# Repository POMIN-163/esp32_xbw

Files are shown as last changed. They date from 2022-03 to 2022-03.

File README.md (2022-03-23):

# 一个基于VGA显示器的小霸王复刻

> 本仓库主要克隆自 [https://github.com/eleree/xbw](https://github.com/eleree/xbw)，做了一些修改、对复现的过程进行了一些完善

## 硬件制作

* 因为我是手焊，所以删去了较难焊的 16pin type-c 并把电阻电容换成了 0805 封装。

* 主板
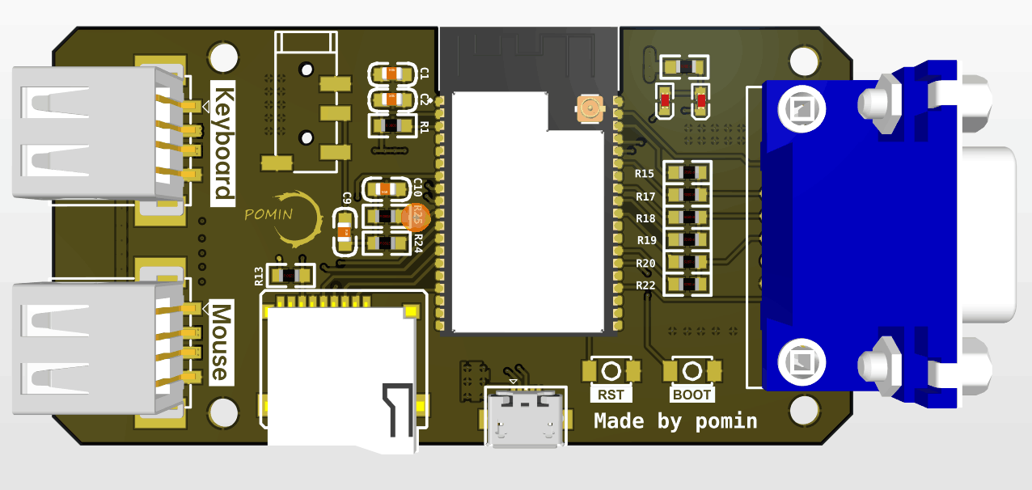
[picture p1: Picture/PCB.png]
    
* 盖板
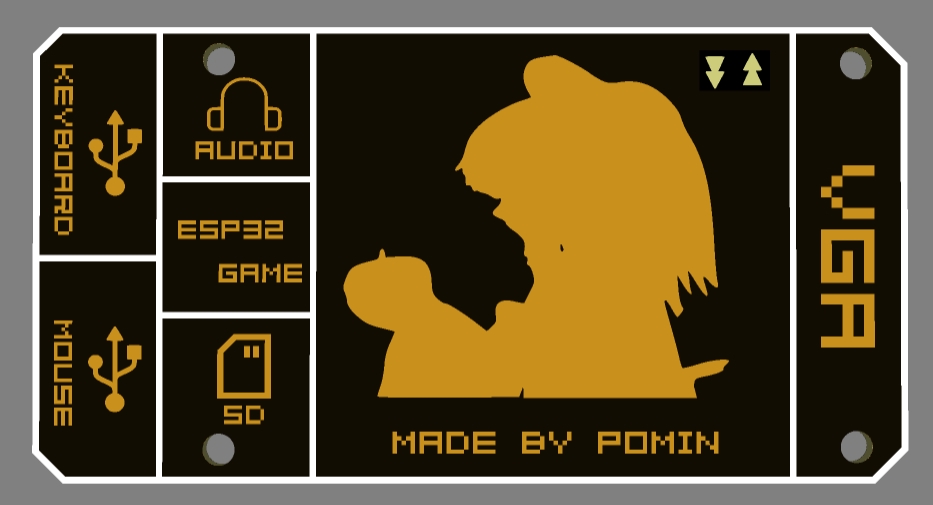
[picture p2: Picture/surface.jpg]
    
* 转接板
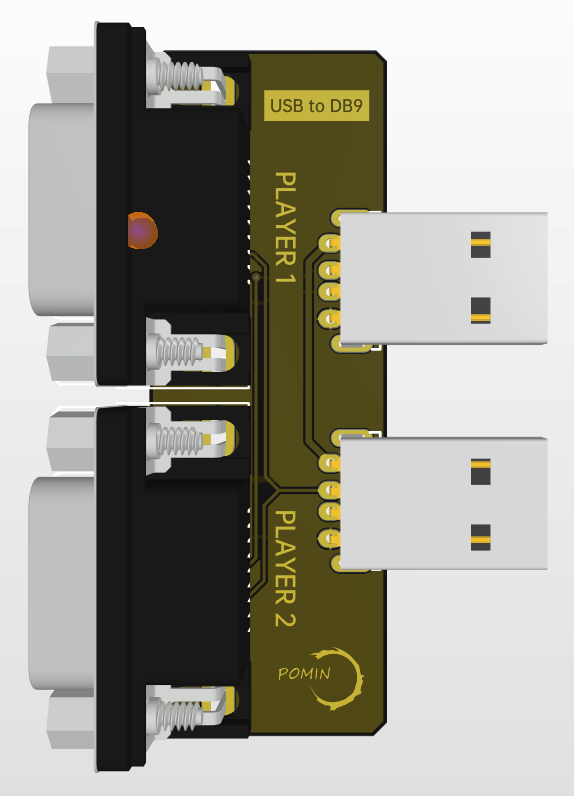
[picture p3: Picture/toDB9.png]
    
* 实物外观
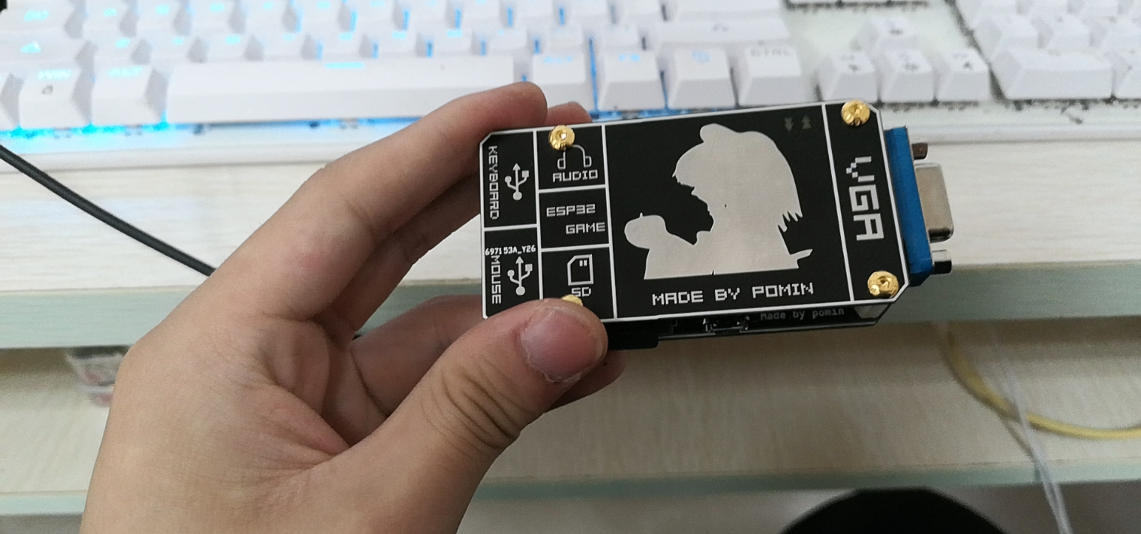
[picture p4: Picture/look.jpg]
    

## 固件编译

* 硬件平台：ESP32-WROVER-E
* 软件平台：ESP32-IDF V3.3.5
* 编译环境：Ubuntu18.04 (WSL)
* Python版本：python2.7

> esp-idf3.3.5 官方文档: [https://docs.espressif.com/projects/esp-idf/zh_CN/v3.3.5/](https://docs.espressif.com/projects/esp-idf/zh_CN/v3.3.5/)

使用的 Ubuntu18.04 中默认 `python` 是 `python2.7`，`python2.7`没有自带`pip`工具，可以我的博客 [https://pomin.top/](https://pomin.top/) 中搜索`python2`的`pip`安装，来按照教程进行安装。

* 克隆储存库并安装

```
cd ~
git clone -b v3.3.5 --recursive https://github.com/espressif/esp-idf.git
cd esp-idf
./install.sh
```

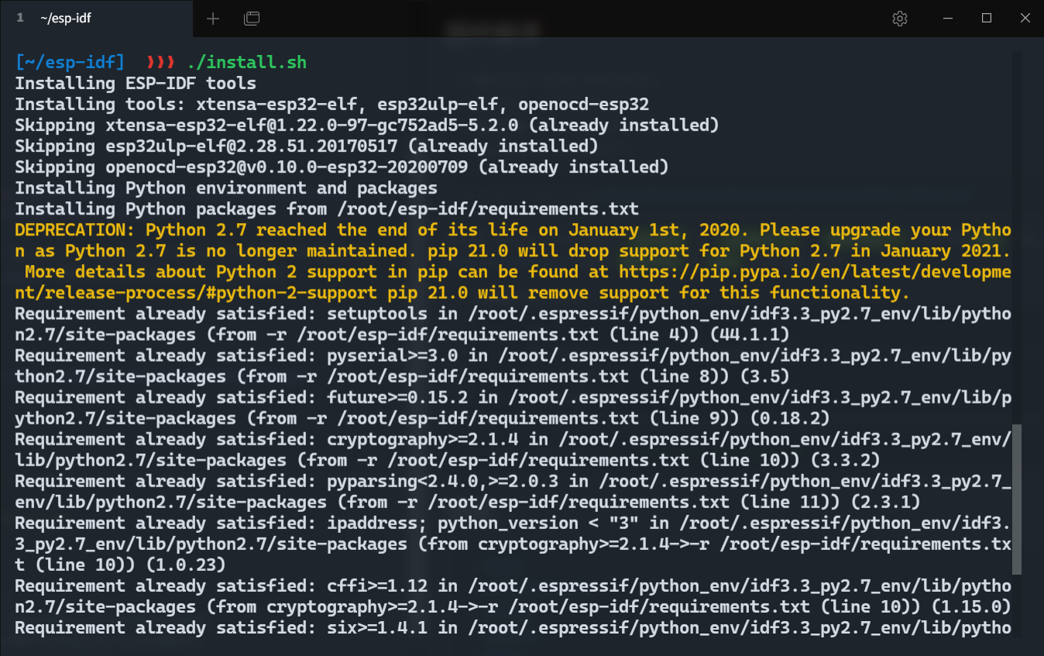
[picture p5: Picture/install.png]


* 外部包含 ( 每次启动终端都要执行 )

```bash
. /root/esp-idf/export.sh
```

* 编译 ( 本仓库采用 gnu make 进行编译 )

```bash
# cd 到仓库的 Code 目录
make -j8 all
```

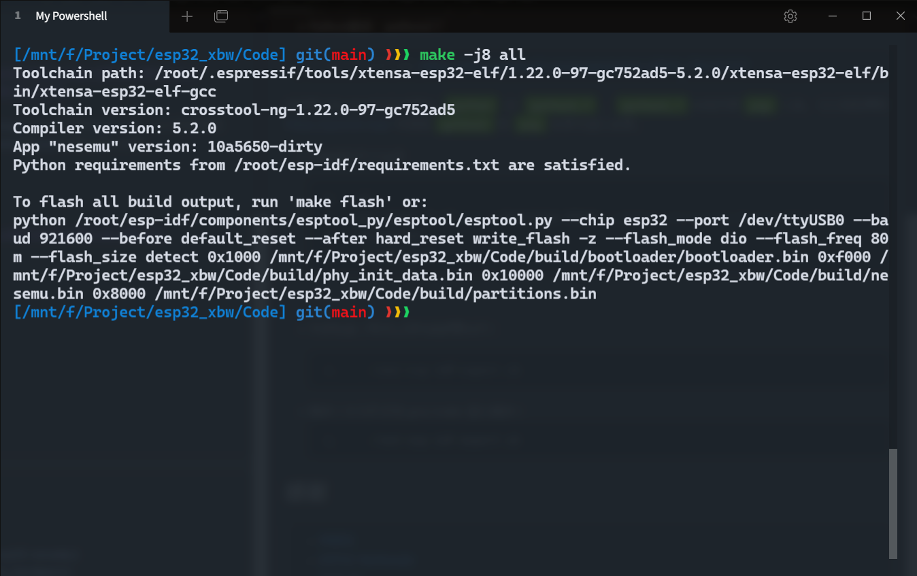
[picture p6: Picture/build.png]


* 烧录 ( 端口号、烧录速率需要自己设置这里是`ttyS22` 也就是 Windows 设备管理器的 `COM22` )

```bash
. ${IDF_PATH}/add_path.sh
esptool.py --chip esp32 --port "/dev/ttyS22" --baud $((230400*4)) write_flash -fs 4MB 0x100000 "build/nesemu.bin"
```

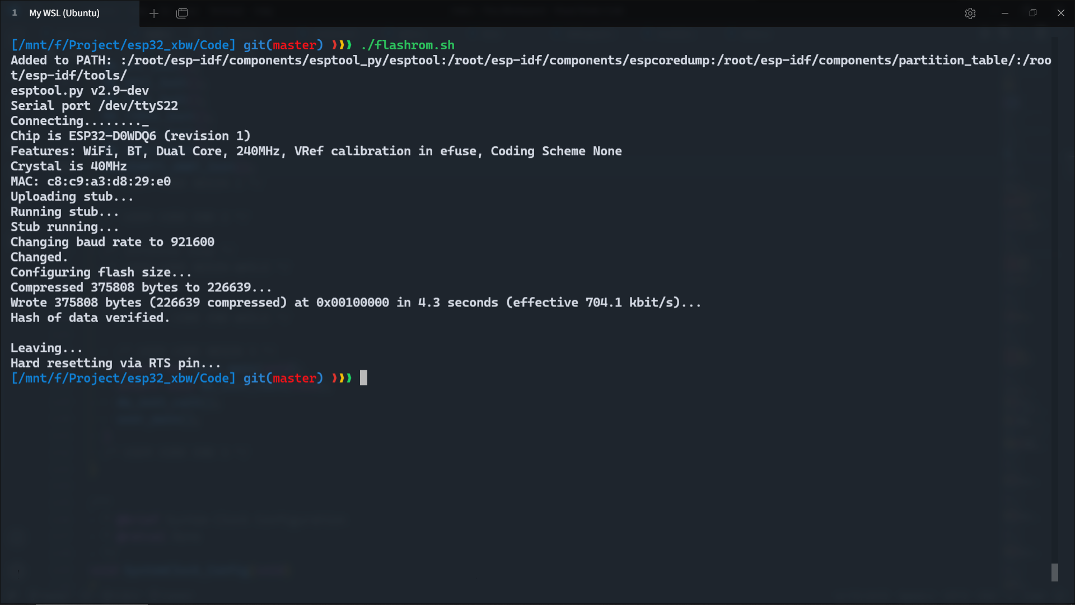
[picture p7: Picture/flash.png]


## 演示

* 运行 `arduino` 的 `fabgl` 库的 `VIC20` 例程玩俄罗斯方块
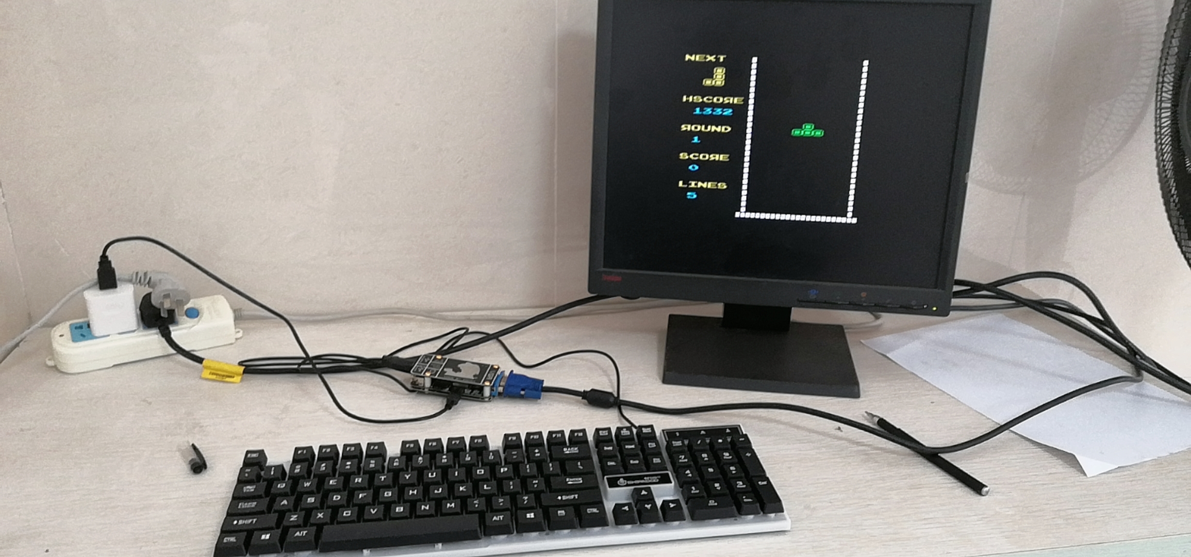
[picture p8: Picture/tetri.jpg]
    
* 运行 [秦秦心](https://github.com/eleree/xbw) 开源的基于`idf3.3.5`开发的 nes 游戏机
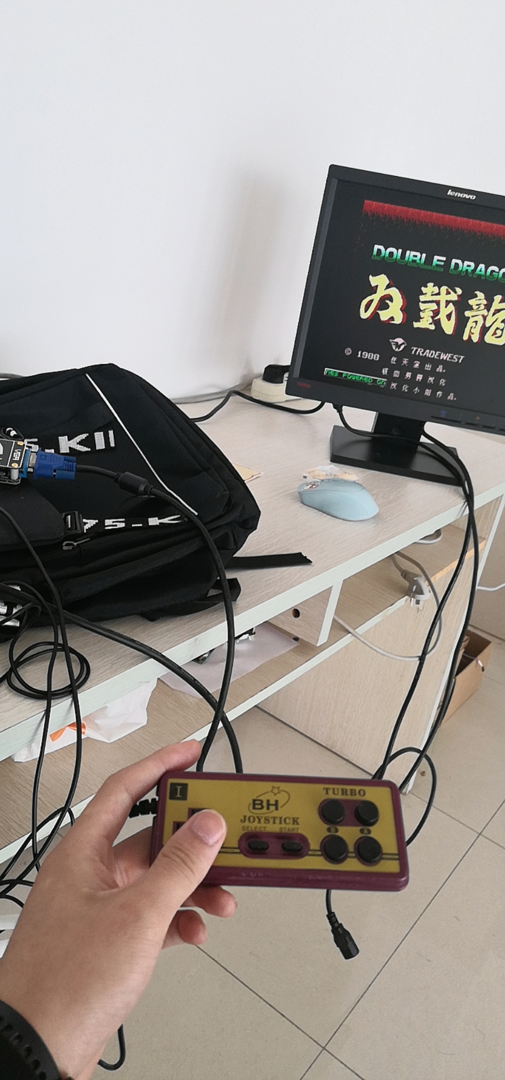
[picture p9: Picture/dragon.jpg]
    

## 感谢以下开源
> * [FABGL](http://www.fabglib.org/)
> * [ESP32-Nofrendo](https://github.com/espressif/esp32-nesemu)
> * [ESPLAY](https://github.com/pebri86/esplay_micro_hardware)
> * [吐槽坑儿](https://space.bilibili.com/31312385)
> * [秦秦心](https://github.com/eleree/xbw)

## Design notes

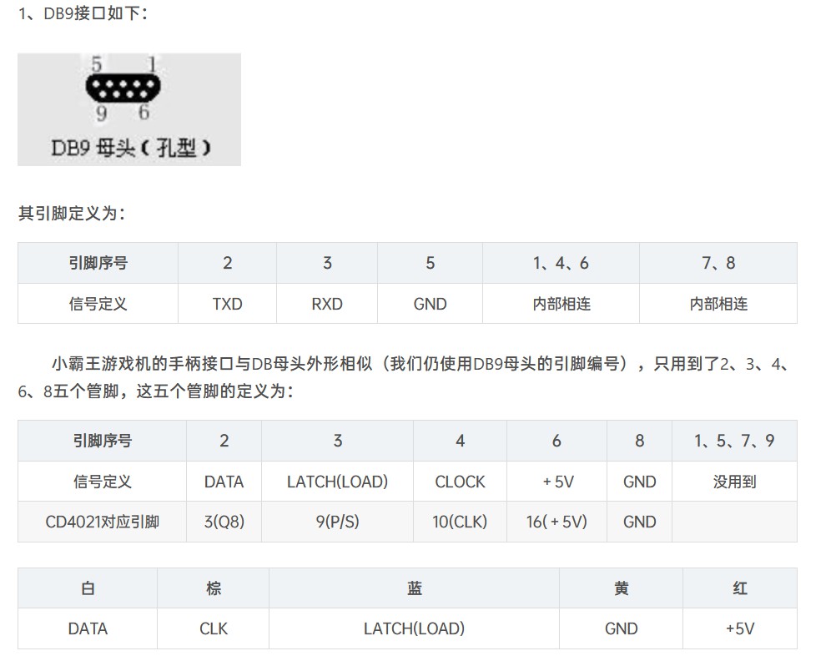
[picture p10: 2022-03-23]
Hardware/USBtoDB9/define.jpg

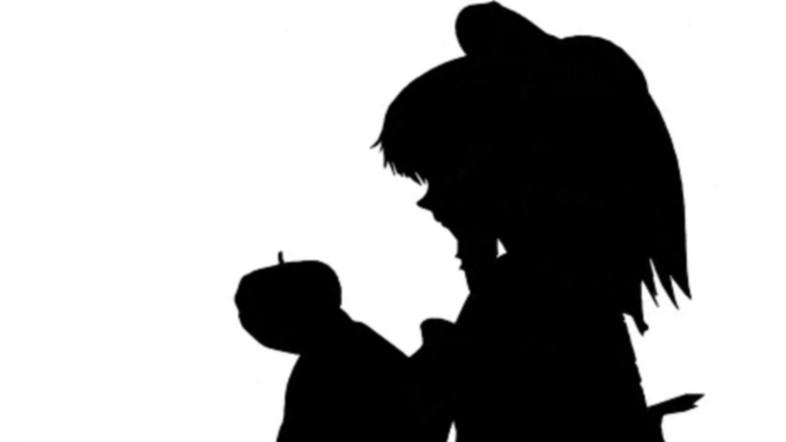
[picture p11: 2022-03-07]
Hardware/surface/apple.jpg

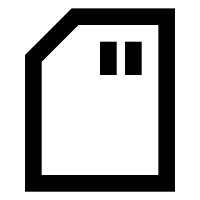
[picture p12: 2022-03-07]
Hardware/surface/SD.png

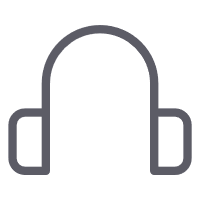
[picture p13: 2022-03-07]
Hardware/surface/audio.png

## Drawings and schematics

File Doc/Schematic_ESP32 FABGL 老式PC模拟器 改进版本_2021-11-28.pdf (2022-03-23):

键盘

音频

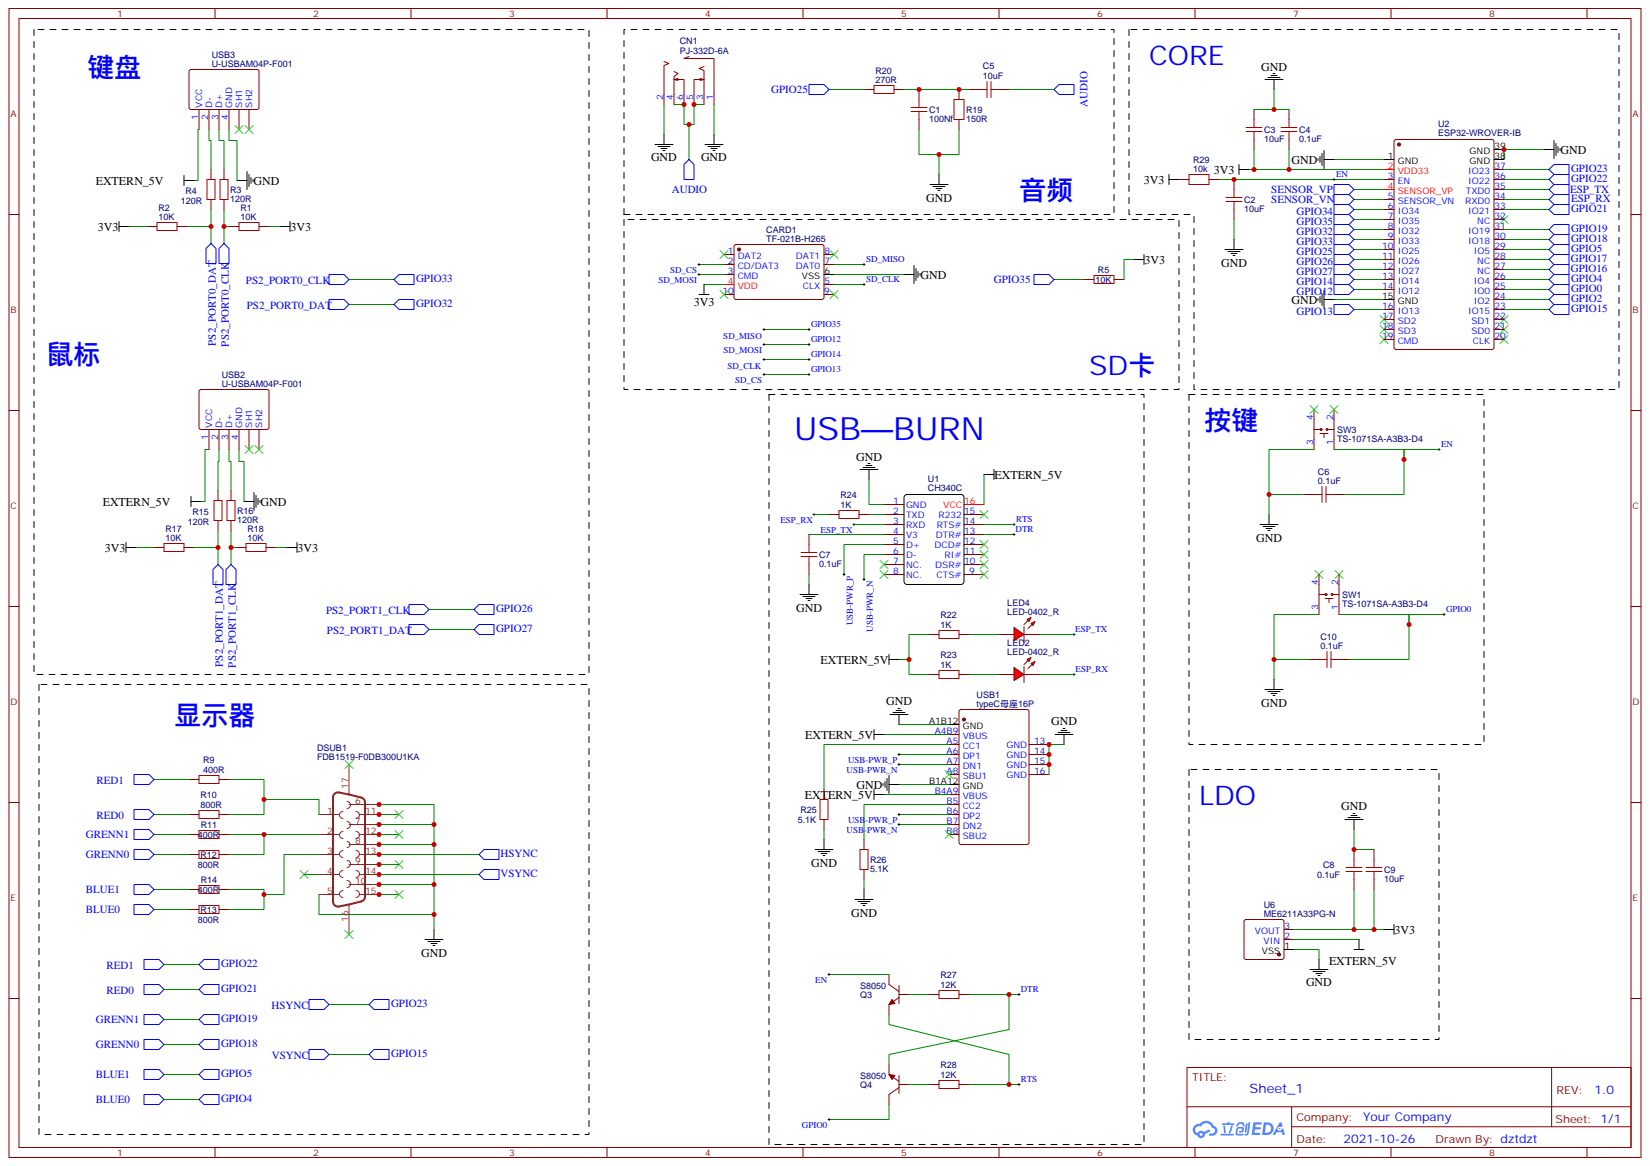
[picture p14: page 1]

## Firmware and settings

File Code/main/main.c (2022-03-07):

#include <vga16.h>

#include "driver/gpio.h"
#include "esp_event.h"
#include "esp_event_loop.h"
#include "esp_partition.h"
#include "esp_system.h"
#include "esp_wifi.h"
#include "freertos/FreeRTOS.h"
#include "nofrendo.h"
#include "nvs_flash.h"
#include "sdcard.h"

#if 0
char *osd_getromdata() {
	char* romdata;
	const esp_partition_t* part;
	spi_flash_mmap_handle_t hrom;
	esp_err_t err;
	nvs_flash_init();
	part=esp_partition_find_first(0x40, 1, NULL);
	if (part==0) printf("Couldn't find rom part!\n");
	err=esp_partition_mmap(part, 0, 3*1024*1024, SPI_FLASH_MMAP_DATA, (const void**)&romdata, &hrom);
	if (err!=ESP_OK) printf("Couldn't map rom part!\n");
	printf("Initialized. ROM@%p\n", romdata);
    return (char*)romdata;
}
#else
const char *SD_BASE_PATH = "/sd";
static char *ROM_DATA = (char *)0x3f800000;

char *osd_getromdata(void) {
    printf("Initialized. ROM@%p\n", ROM_DATA);
    return (char *)ROM_DATA;
}

#endif

esp_err_t event_handler(void *ctx, system_event_t *event) { return ESP_OK; }

void sdspi_test(void) {
    vTaskDelay(3000);
    sdcard_open("/sd");
    int count = sdcard_get_files_count("/sd/sd");
    printf("sd card files :%d\r\n", count);
    size_t file_size = sdcard_get_filesize("/sd/sd/NOTICE.txt");
    printf("sd card file size :%d\r\n", file_size);
}

void ui_init(void);
char *ui_file_chooser(const char *path, const char *filter, int currentItem,
                      char *title);
void ui_clear_screen(void);

char *romPath = NULL;
void vfs_test(void) {
    FILE *f = fopen("/sd/hello.txt", "w");
    if (f == NULL) {
        return;
    }
    fprintf(f, "Hello %s!\n", "world");
    fclose(f);
}
void load_rom(void) {
    esp_err_t ret = sdcard_open(SD_BASE_PATH);
    if (ret != ESP_OK) {
        printf("failed to open sd card\n");
        return NULL;
    }
    romPath = ui_file_chooser("/sd/roms", ".nes", 0, "Select ROM");
    if (romPath == NULL) {
        printf("No ROM selected\n");
        return;
    }
    printf("ROM: %s\n", romPath);
    sdcard_close();
    ROM_DATA = malloc(3 * 1024 * 1024);
    if (!romPath) {
        printf("osd_getromdata: Reading from flash.\n");

        // copy from flash
        // spi_flash_mmap_handle_t hrom;
        const esp_partition_t *part = esp_partition_find_first(0x40, 1, NULL);
        if (part == 0) {
            printf("esp_partition_find_first failed.\n");
            abort();
        }

        esp_err_t err = esp_partition_read(part, 0, (void *)ROM_DATA, 0x100000);
        if (err != ESP_OK) {
            printf("esp_partition_read failed. size = %x (%d)\n", part->size,
                   err);
            abort();
        }
    } else {
        printf("osd_getromdata: Reading from sdcard.\n");

        // copy from SD card
        esp_err_t r = sdcard_open(SD_BASE_PATH);
        if (r != ESP_OK) {
            abort();
        }

        // display_clear(0);
        // display_show_hourglass();
        size_t file_size = sdcard_get_filesize(romPath);
        printf("sd card file size :%d\r\n", file_size);
        vfs_test();
        size_t fileSize = sdcard_copy_file_to_memory(romPath, ROM_DATA);
        printf("app_main: fileSize=%d\n", fileSize);
        if (fileSize == 0) {
            abort();
        }

        r = sdcard_close();
        if (r != ESP_OK) {
            abort();
        }

        free(romPath);
    }
}

int app_main(void) {
    vga_init();
    vga_write_frame(0, 0, 320, 240, NULL);
    ui_init();
    load_rom();
    ui_clear_screen();
    printf("starting esp32 nofrendo\r\n");
    printf("NoFrendo start!\n");
    nofrendo_main(0, NULL);
    printf("NoFrendo died? WtF?\n");
    asm("break.n 1");
    return 0;
}

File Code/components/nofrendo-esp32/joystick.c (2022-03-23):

#include <stdio.h>
#include "freertos/FreeRTOS.h"
#include "freertos/task.h"
#include "freertos/semphr.h"
#include "freertos/queue.h"

#include "driver/gpio.h"
#include "soc/gpio_struct.h"
#include "psxcontroller.h"
#include "sdkconfig.h"

#pragma GCC optimize ("O0")

#define DELAY() asm("nop; nop; nop; nop;nop; nop; nop; nop;nop; nop; nop; nop;nop; nop; nop; nop;")

#if CONFIG_HW_JOYSTICK_ENABALE

void joystickDelay(void)
{
   DELAY();
   for (int delay = 0; delay < 100; delay++)
   {
   };
}

int digitalRead(uint8_t pin)
{
   if (pin < 32)
   {
      return (GPIO.in >> pin) & 0x1;
   }
   else
   {
      return (GPIO.in1.val >> (pin - 32)) & 0x1;
   }
   return 0;
}

void IRAM_ATTR digitalWrite(uint8_t pin, uint8_t val)
{
   if (val)
   {
      if (pin < 32)
      {
         GPIO.out_w1ts = ((uint32_t)1 << pin);
      }
      else if (pin < 34)
      {
         GPIO.out1_w1ts.val = ((uint32_t)1 << (pin - 32));
      }
   }
   else
   {
      if (pin < 32)
      {
         GPIO.out_w1tc = ((uint32_t)1 << pin);
      }
      else if (pin < 34)
      {
         GPIO.out1_w1tc.val = ((uint32_t)1 << (pin - 32));
      }
   }
}
// todo 读取手柄值
int joystickReadInput()
{
   uint32_t clkPin = CONFIG_HW_JOYSTICK_CLK;     // 27
   uint32_t latchPin = CONFIG_HW_JOYSTICK_LATCH; // 32
   uint32_t data1Pin = CONFIG_HW_JOYSTICK_DAT1;  // 33
   uint32_t data2Pin = CONFIG_HW_JOYSTICK_DAT2;  // 26
   uint16_t key1 = 0;
   uint16_t key2 = 0;
   digitalWrite(latchPin, 1);
   joystickDelay();
   digitalWrite(latchPin, 0);
   joystickDelay();
         if (digitalRead(data1Pin))
         key1 |= 1;
      if (digitalRead(data2Pin))
         key2 |= 1;

   digitalWrite(clkPin, 0);
   joystickDelay();
   for (int i = 0; i < 8; i++)
   {
      key1 <<= 1;
      key2 <<= 1;
      digitalWrite(clkPin, 1);
      joystickDelay();
      if (digitalRead(data1Pin))
         key1 |= 1;
      if (digitalRead(data2Pin))
         key2 |= 1;
      digitalWrite(clkPin, 0);
      joystickDelay();
   }
   digitalWrite(clkPin, 0);
   key1 >>= 1;
   key2 >>= 1;
   //printf("gpio in 0x%x in1 0x%x\r\n", GPIO.in, GPIO.in1.val);
   //if( key1 != 0xff)
   //   printf("read key1 0x%x key2 0x%x\r\n", key1, key2);
   return key1 | key2 << 8;
}

void joystickInit()
{
   printf("Joystick controller enabled.\n");
   gpio_config_t gpioconf[2] = {
       {.pin_bit_mask = (1ULL << CONFIG_HW_JOYSTICK_CLK) | (1ULL << CONFIG_HW_JOYSTICK_LATCH),
        .mode = GPIO_MODE_OUTPUT,
        .pull_up_en = GPIO_PULLUP_DISABLE,
        .pull_down_en = GPIO_PULLDOWN_DISABLE,
        .intr_type = GPIO_PIN_INTR_DISABLE},
       {.pin_bit_mask = (1ULL << CONFIG_HW_JOYSTICK_DAT1) | (1ULL << CONFIG_HW_JOYSTICK_DAT2),
        .mode = GPIO_MODE_INPUT,
        .pull_up_en = GPIO_PULLUP_ENABLE,
        .pull_down_en = GPIO_PULLDOWN_DISABLE,
        .intr_type = GPIO_PIN_INTR_DISABLE}};
   gpio_config(&gpioconf[0]);
   gpio_config(&gpioconf[1]);
}
#else
int joystickReadInput()
{
   return 0xFFFF;
}

void joystickInit()
{
   printf("Joystick controller disabled in menuconfig; no input enabled.\n");
}
#endif

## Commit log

2022-03-07 修改readme
2022-03-23 made hardware ok
    [ESP32.SchDoc, USB to DB9.SchDoc, USBtoDB9.PrjPcb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]
